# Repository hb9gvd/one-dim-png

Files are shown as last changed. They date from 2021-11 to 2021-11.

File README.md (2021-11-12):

# One Dim Pong
Arduino code and PCB Files, either Kicad and ready-to-order Gerber Files for One Dimensional Pong Game.
This repository exists for users to get files, open issues and make contributions.

To get started see [Firmware versions](#firmware-versions) part or look table of contents for more.

Table of contents
=================
* [Firmware versions](#firmware-versions)
* [Hardware schematic](#schematic)

Firmware Versions
============
To use with 100ms pulse coin counter 
[Arduino code and used libraries](./software/).

Schematic
============
Repository has updated Schematic made with Kicad. Some more information could be found 
[here](./hardware/kicad/).
Altough, find here printable 
[Schematic](./hardware/one-dim-pong.pdf) 
and have a look to the 
[PCB picture](./hardware/One-Dim-Pong-3D-V1.png).

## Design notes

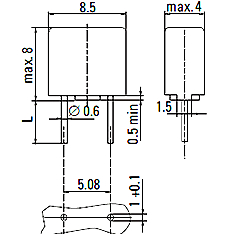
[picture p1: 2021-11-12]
hardware/THT-Fuse.jpg

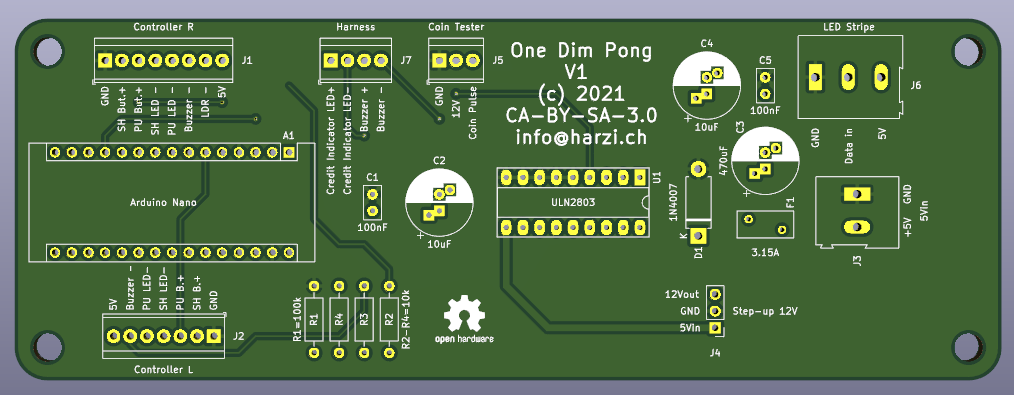
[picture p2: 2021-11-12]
hardware/One-Dim-Pong-3D-V1.png

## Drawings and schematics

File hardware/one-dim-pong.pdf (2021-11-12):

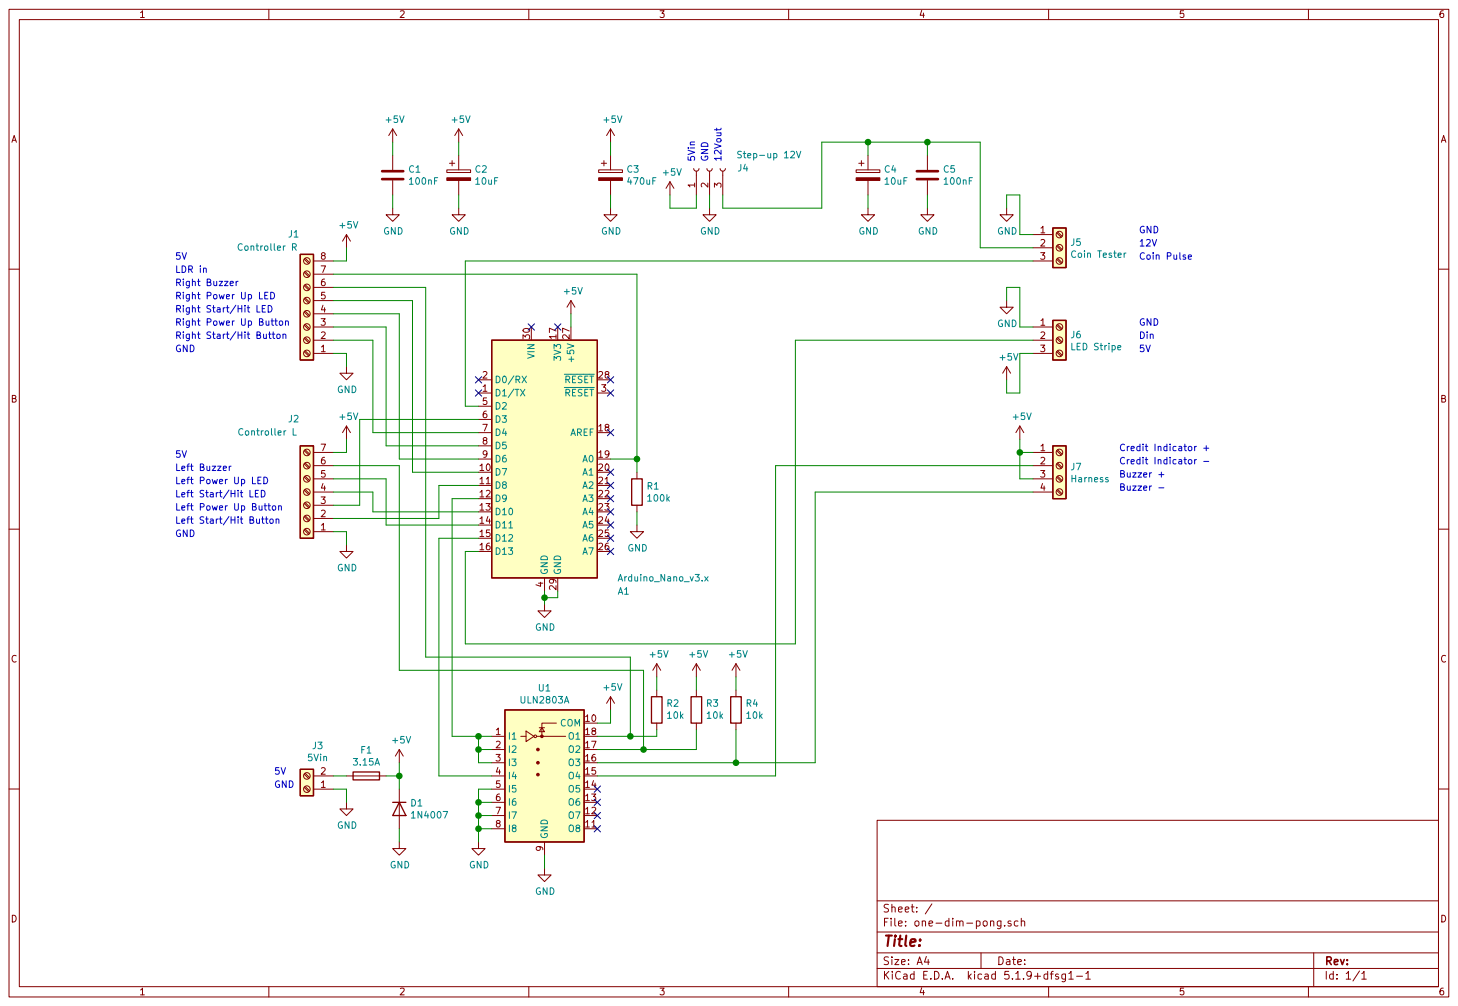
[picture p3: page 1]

Credit Indicator - Coin Pulse

Buzzer + Right Buzzer LDR in

Right Power Up LED
Right Start/Hit LED

Left Power Up LED
Buzzer - GND
Left Start/Hit LED
Left Power Up Button
Left Start/Hit Button

File: one-dim-pong.sch Sheet: / GND

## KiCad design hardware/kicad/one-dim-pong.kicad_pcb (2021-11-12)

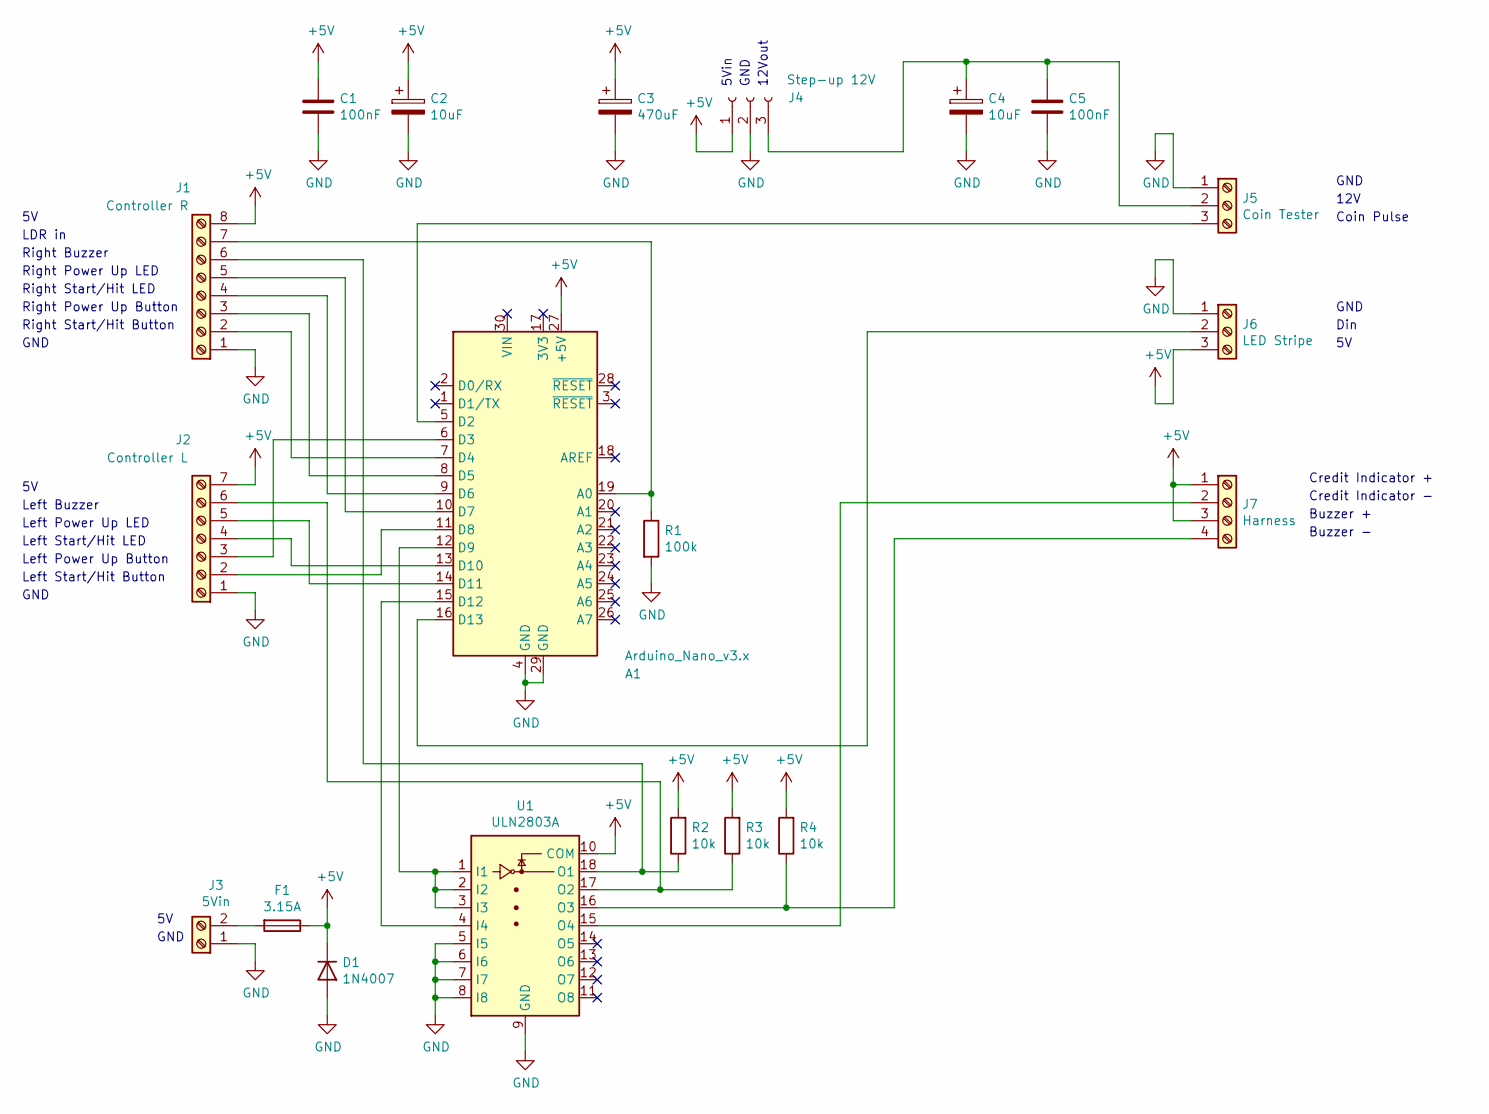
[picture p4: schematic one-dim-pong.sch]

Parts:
A1: Arduino_Nano_v3.x; Arduino_Nano
C1, C5: 100nF; C_Disc_D5.0mm_W2.5mm_P2.50mm
C2, C4: 10uF; CP_Radial_D10.0mm_P2.50mm_P5.00mm
C3: 470uF; CP_Radial_D10.0mm_P2.50mm_P5.00mm
D1: 1N4007; D_DO-15_P10.16mm_Horizontal
F1: 3.15A; Fuse_BelFuse_0ZRE0008FF_L8.3mm_W3.8mm
J1: Controller R; TerminalBlock_TE_282834-8_1x08_P2.54mm_Horizontal
J2: Controller L; TerminalBlock_TE_282834-7_1x07_P2.54mm_Horizontal
J3: 5Vin; TerminalBlock_Altech_AK300-2_P5.00mm
J4: Step-up 12V; PinHeader_1x03_P2.54mm_Vertical
J5: Coin Tester; TerminalBlock_TE_282834-3_1x03_P2.54mm_Horizontal
J6: LED Stripe; TerminalBlock_Altech_AK300-3_P5.00mm
J7: Harness; TerminalBlock_TE_282834-4_1x04_P2.54mm_Horizontal
R1: 100k; R_Axial_DIN0207_L6.3mm_D2.5mm_P10.16mm_Horizontal
R2, R3, R4: 10k; R_Axial_DIN0207_L6.3mm_D2.5mm_P10.16mm_Horizontal
U1: ULN2803A; DIP-18_W7.62mm_Socket_LongPads

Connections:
+5V: A1.27 (+5V), C1.1, C2.1, C3.1, D1.1 (K), F1.1, J1.8, J2.7, J4.1, J6.3, J7.1, J7.3, R2.2, R3.2, R4.2, U1.10 (COM)
GND: A1.4 (GND), A1.29 (GND), C1.2, C2.2, C3.2, C4.2, C5.2, D1.2 (A), J1.1, J2.1, J3.1, J4.2, J5.1, J6.1, R1.2, U1.5 (I5), U1.6 (I6), U1.7 (I7), U1.8 (I8), U1.9 (GND)
unnamed: A1.5 (D2), J5.3
unnamed: A1.6 (D3), J2.3
unnamed: A1.7 (D4), J1.2
unnamed: A1.8 (D5), J1.3
unnamed: A1.9 (D6), J1.4
unnamed: A1.10 (D7), J1.5
unnamed: A1.11 (D8), J2.2
unnamed: A1.12 (D9), U1.1 (I1), U1.2 (I2), U1.3 (I3)
unnamed: A1.13 (D10), J2.4
unnamed: A1.14 (D11), J2.5
unnamed: A1.15 (D12), U1.4 (I4)
unnamed: A1.16 (D13), J6.2
unnamed: A1.19 (A0), J1.7, R1.1
unnamed: C4.1, C5.1, J4.3, J5.2
unnamed: F1.2, J3.2
unnamed: J1.6, R2.1, U1.18 (O1)
unnamed: J2.6, R3.1, U1.17 (O2)
unnamed: J7.2, U1.15 (O4)
unnamed: J7.4, R4.1, U1.16 (O3)

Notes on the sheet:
Credit Indicator -
Credit Indicator +
Buzzer +
Buzzer -
5Vin
GND
12Vout
12V
Coin Pulse
Right Start/Hit Button
Right Power Up Button
Right Start/Hit LED
Right Power Up LED
Right Buzzer
LDR in
Left Start/Hit Button
Left Power Up Button
Left Start/Hit LED
Left Power Up LED
Left Buzzer
Din

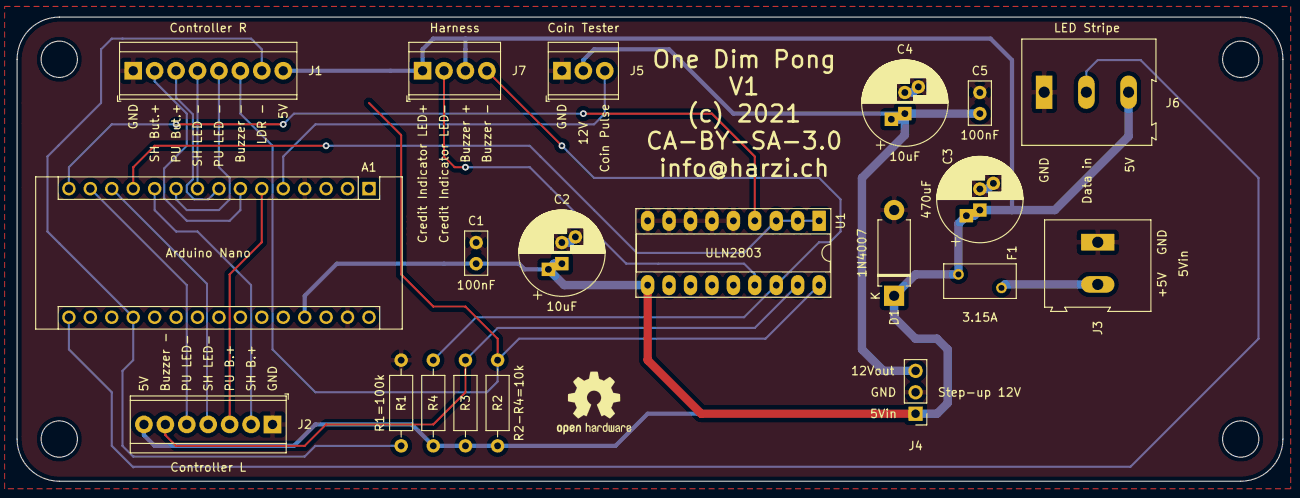
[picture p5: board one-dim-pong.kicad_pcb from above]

Board: 2 copper layers, 150.0 x 55.0 mm, 20 parts (0 on the bottom side), 21 nets.

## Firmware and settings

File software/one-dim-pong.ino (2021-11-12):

/*
 * Arduino 1D Pong Game with (60) WS2812B LEDs
 *
 * Copyright (C) 2015  B.Stultiens
 *
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
 * You should have received a copy of the GNU General Public License
 * along with this program.  If not, see <http://www.gnu.org/licenses/>.
 */
#include "Adafruit_NeoPixel.h"
#include "notes.h"

#define NELEM(x)		(sizeof(x) / sizeof((x)[0]))

int sensorPin    =    A0;   // select the input pin for ldr
int sensorValue  =     0;   // variable to store the value coming from the sensor
uint8_t bright;
#define minValue      930   // min. sensor value for lowest brightness
#define maxValue      1020  // max. sensor value for highest brightness
#define minBrightAnim 255   // lowest brightness
#define maxBrightAnim 255   // highest brightness

#define PIN_WSDATA    13  // LED data
#define PIN_BUT_LS    8   // Right start/hit button
#define PIN_BUT_LP    3   // Right power-up button
#define PIN_BUT_RS    4   // Left start/hit button
#define PIN_BUT_RP    5   // Left power-up button
#define PIN_BUT_COIN  2   // Coin pulse
#define PIN_SOUND     9   // Buzzer output (PB1/OC1A)
#define PIN_LED_RP    6   // Right start/hit button light
#define PIN_LED_RS    11  // Right power-up button light
#define PIN_LED_LP    10  // Left power-up button light
#define PIN_LED_LS    7   // Left start/hit button light
#define PIN_COINS_AVAILABLE 12

#define BL_NONE		0xff		// State changes of the button LEDs
#define BL_LS			0x01
#define BL_LP			0x02
#define BL_RS			0x04
#define BL_RP			0x08
#define BL_ALL		0x0f

#define NPIXELS			90		// Number of pixels to handle

#define H_STEPS			1542		// HSV maximum hue +1
#define H_YELLOW		257		// Hue for (hard) yellow color

#define ZONE_SIZE		7		// Bounce-back zone size
#define SHOW_LO			12		// Score dots intensity background
#define SHOW_HI			48		// Score dots intensity foreground
#define WIN_POINTS		5		// Points needed to win
#define TONE_INTERVAL		5		// Not every ball move should give a sound
int CREDIT  =       0;
#define COIN_PULSE  150

Adafruit_NeoPixel one_d = Adafruit_NeoPixel(NPIXELS, PIN_WSDATA, NEO_GRB | NEO_KHZ800);

// Events from buttons and timers
#define EV_BUT_LS_PRESS		0x01
#define EV_BUT_RS_PRESS		0x02
#define EV_BUT_LP_PRESS		0x04
#define EV_BUT_RP_PRESS		0x08
#define EV_COIN_INSERTED           0x10

#define EV_TIMER		0x20
#define EV_TIMEOUT		0x40
#define EV_TONETIMER		0x80

#define TIME_DEBOUNCE		8
#define TIME_IDLE		40
#define TIME_START_TIMEOUT	20000		// Go idle if nothing happens
#define TIME_RESUME_TIMEOUT	7500		// Auto-fire after timeout
#define TIME_BALL_BLINK		150
#define TIME_SPEED_MIN		10
#define TIME_SPEED_INTERVAL	3
#define TIME_POINT_BLINK	233
#define TIME_WIN_BLINK		85
#define TIME_LOCKOUT		250		// Prevent fast button-press to max. 4 times/s

#define TIME_TONE_SERVE		50		// Sound durations
#define TIME_TONE_BOUNCE	50
#define TIME_TONE_MOVE		25
#define TIME_TONE_SCORE		50

enum {
	ST_IDLE = 0,
	ST_START_L,
	ST_START_R,
	ST_MOVE_LR,
	ST_MOVE_RL,
	ST_ZONE_L,
	ST_ZONE_R,
	ST_POINT_L,
	ST_POINT_R,
	ST_RESUME_L,
	ST_RESUME_R,
	ST_WIN_L,
	ST_WIN_R,
};

static uint32_t oldtime;	// Previous' loop millis() value
static uint8_t thestate;	// Game state

static uint8_t bstate_ls;	// Button states
static uint8_t bstate_rs;
static uint8_t bstate_lp;
static uint8_t bstate_rp;
static uint8_t bstate_cn;
static uint8_t debtmr_ls;	// Button debounce timers
static uint8_t debtmr_rs;
static uint8_t debtmr_lp;
static uint8_t debtmr_rp;
static uint8_t debtmr_cn;
static uint16_t timer;		// General timer
static uint16_t timeout;	// Timeout timer (auto-start and goto idle)
static uint16_t tonetimer;	// Tone duration timer
static uint16_t lockout_l;	// Lockout timer to prevent pushing too often
static uint16_t lockout_r;
static uint16_t lock_coin;  // Timer to asure one CREDIT per COIN_PULSE only
static uint8_t ballblinkstate;	// Blinking ball at edge on/off
static uint8_t pointblinkcount;	// Blinking point when a side scores
static uint8_t ballpos;		// Current position of the ball
static uint16_t speed;		// Time between ball moves
static uint8_t speedup;		// Faster and faster replies counter
static uint8_t points_l;	// Score
static uint8_t points_r;
static uint8_t zone_l;		// Hit back zone
static uint8_t zone_r;
static uint8_t boost_l;		// Set if user boosted speed last round
static uint8_t boost_r;
static uint8_t boosted;		// Set if any user boosted until the ball reaches opposite side
static uint8_t tonecount;	// Interval counter for sound during move
static uint8_t tuneidx;		// Index to the running tune

static uint16_t ballh;		// Ball hue when moving boosted

// Twinkling lights when boosted (comet trail parts breaking off)
#define NTWINKLES	(NPIXELS / 8)
static struct {
	uint8_t		v;
	uint8_t 	pos;
	uint16_t	h;
} twinkles[NTWINKLES];

static uint32_t prng_val;	// Local random number generator state

typedef struct __note_t {
	uint8_t		note;
	uint16_t	duration;
} note_t;

/* Tone pitch table for 16MHz crystal */
static const uint16_t tone_pitch[NTONE_PITCH] PROGMEM = {
	61155, 57722, 54482, 51424, 48538, 45814, 43242, 40815, 38524, 36362 /* == 220Hz */, 34321, 32395,
	30577, 28860, 27240, 25711, 24268, 22906, 21620, 20407, 19261, 18180 /* == 440Hz */, 17160, 16197,
	15288, 14429, 13619, 12855, 12133, 11452, 10809, 10203,  9630,  9089 /* == 880Hz */,  8579,  8098,
	 7643,  7214,  6809,  6427,  6066,  5725,  5404,  5101,  4814,  4544,  4289,  4048,
	 3821,  3606,  3404,  3213,  3032,  2862,  2701,  2550,  2406,  2271,  2144,  2023,
	 1910,
};
static const note_t tune_win[] PROGMEM = {
	{ NOTE_Gs6, DUR_1_16 },
	{ NOTE_A6, DUR_1_16 },
	{ NOTE_Gs6, DUR_1_16 },
	{ NOTE_E6, DUR_1_16 },
	{ NOTE_Gs6, DUR_1_16 },
	{ NOTE_A6, DUR_1_16 },
	{ NOTE_Gs6, DUR_1_16 },
	{ NOTE_E6, DUR_1_16 },
	{ 0, DUR_1_8 },
	{ NOTE_D4, DUR_1_8 },
	{ NOTE_D4, DUR_1_8 },
	{ NOTE_B3, DUR_1_8 },
	{ NOTE_E4, DUR_1_8 },
	{ NOTE_D4, DUR_1_4 },
	{ NOTE_B3, DUR_1_4 },
	{ NOTE_D4, DUR_1_8 },
	{ NOTE_D4, DUR_1_8 },
	{ NOTE_B3, DUR_1_8 },
	{ NOTE_E4, DUR_1_8 },
	{ NOTE_D4, DUR_1_4 },
	{ NOTE_B3, DUR_1_4 },
};

#define sound_off()	do { TCCR1A = _BV(COM1A1); /* Set clear output */ } while(0)

/*
 * Local very fast Pseudo Random Number Generator (PRNG)
 * based on a simple LFSR design.
 */
static inline uint8_t lfsr_prng(void)
{
	uint8_t c = prng_val & 1;
	prng_val >>= 1;
	if(c)
		prng_val ^= 0xa6a6a6a6;
	return prng_val;
}

/*
 * Return the current state of a button.
 * Returns non-zero on button pressed.
 */
static inline uint8_t button_is_down(uint8_t pin)
{
	switch(pin) {
	case PIN_BUT_LS:	    return !debtmr_ls && !bstate_ls;
	case PIN_BUT_RS:	    return !debtmr_rs && !bstate_rs;
	case PIN_BUT_LP:	    return !debtmr_lp && !bstate_lp;
	case PIN_BUT_RP:	    return !debtmr_rp && !bstate_rp;
  case PIN_BUT_COIN:    return !debtmr_cn && !bstate_cn;
	}
	return 0;
}

/*
 * Debounce a button and return an event at the rising edge of the detection.
 * The rising edge ensures that there is no delay from pressing the button and
 * the event propagating. It is a prerequisite that the input line is not
 * glitchy.
 * A release event may be generated if the routine is slightly modified.
 */
static inline uint8_t do_debounce(uint8_t tdiff, uint8_t *bstate, uint8_t *debtmr, uint8_t pin, uint8_t ev)
{
	if(0 == *debtmr) {
		uint8_t state = digitalRead(pin);
		if(state != *bstate) {
			*debtmr = TIME_DEBOUNCE;
			if(!(*bstate = state))
				return ev;	// Event on High-to-Low transition of input
			// else
			//  return release_event_value
		}
	} else {
		if(*debtmr >= tdiff)
			*debtmr -= tdiff;
		else
			*debtmr = 0;
	}
	return 0;
}

/*
 * Timer countdown and return an event on timer reaching zero.
 */
static inline uint8_t do_timer(uint8_t tdiff, uint16_t *tmr, uint8_t ev)
{
	if(0 != *tmr) {
		if(*tmr >= tdiff)
			*tmr -= tdiff;	// Timer countdown
		else
			*tmr = 0;
		// Set event when done counting
		if(0 == *tmr)
			return ev;
	}
	return 0;
}

/*
 * Set the speaker to generate a tone
 */
static inline void set_tone(uint16_t note, uint16_t duration)
{
	tonetimer = duration;
	if(note && note <= NTONE_PITCH) {
		OCR1A = pgm_read_word(&tone_pitch[note-1]);
		TCCR1A = _BV(COM1A0);	/* Set toggle output */
		TCNT1 = 0;
	} else
		sound_off();
}

/*
 * Play the next note of the tune
 */
static inline void tune_next()
{
	if(tuneidx < NELEM(tune_win)) {
		uint16_t n = pgm_read_byte(&tune_win[tuneidx].note);
		uint16_t d = pgm_read_word(&tune_win[tuneidx].duration);
		set_tone(n, d);
		tuneidx++;
	} else
		set_tone(0, 0);
}

/*
 * Draw the left and right zones where the ball may be hit back.
 */
static void draw_sides()
{
	for(uint8_t i = 0; i < zone_l-1; i++) {
		one_d.setPixelColor(i, 0, 64, 64);
	}
	one_d.setPixelColor(0, 0, 64, 64);
	for(uint8_t i = 0; i < zone_r-1; i++) {
		one_d.setPixelColor(NPIXELS-1-i, 0, 64, 64);
	}
	one_d.setPixelColor(NPIXELS-1, 0, 64, 64);
}

/*
 * Draw the ball with a tail of five pixels in diminishing intensity.
 * The ball changes color when boosted and there is a chance of parts "falling
 * off" which will twinkle for a while.
 */
static void draw_ball(int8_t dir, uint8_t pos)
{
	uint8_t c = 255;
	uint8_t tail;

	/* Adjust the tail-length to the speed of the ball.
	 * We use 'timer' here because a boost changes the speed and the timer
	 * is set before we draw the ball.
	 */
	if(timer <= 3)
		tail = 7;	// High speed, long tail
	else if(timer <= 12)
		tail = 6;
	else
		tail = 5;	// Default to 5 pixels

	if(boosted) {
		ballh += 75;	// About three times round the circle on the course
		if(ballh >= H_STEPS)
			ballh -= H_STEPS;
		/* 1 in 4 chance of adding a twinkle */
		if(!(lfsr_prng() & 0x03)) {
			for(uint8_t i = 0; i < NELEM(twinkles); i++) {
				if(!twinkles[i].v) {
					/* Add to first free slot */
					twinkles[i].v = 255;
					twinkles[i].pos = pos;
					twinkles[i].h = ballh;
					break;
				}
			}
		}
		/* Draw color ball */
		for(uint8_t i = 0; i < tail && pos >= 0 && pos < NPIXELS; i++) {
			one_d.setPixelColorHsv(pos, ballh, 255, c);
			c >>= 1;
			pos -= dir;
		}
		/* Add twinkling lights */
		for(uint8_t i = 0; i < NELEM(twinkles); i++) {
			if(twinkles[i].v) {
				one_d.setPixelColorHsv(twinkles[i].pos, twinkles[i].h, 128, twinkles[i].v);
				/* 1 in 8 chance to increase the intensity */
				if(!(lfsr_prng() & 0x07)) {
					twinkles[i].v <<= 4;
					twinkles[i].v |= 0x0f;
				} else {
					twinkles[i].v >>= 1;
				}
			}
		}
	} else {
		for(uint8_t i = 0; i < tail && pos >= 0 && pos < NPIXELS; i++) {
			one_d.setPixelColor(pos, c, c, 0);
			c >>= 1;
			pos -= dir;
		}
	}

}

/*
 * Draw the playing field consisting of the zones and the points scored so far.
 */
static void draw_course(uint8_t v)
{
	one_d.clear();
	draw_sides();
	if(v) {
		for(uint8_t i = 0; i < points_l; i++) {
			one_d.setPixelColor(NPIXELS/2-1-(2*i+0), v, 0, 0);
			one_d.setPixelColor(NPIXELS/2-1-(2*i+1), v, 0, 0);
		}
		for(uint8_t i = 0; i < points_r; i++) {
			one_d.setPixelColor(NPIXELS/2+(2*i+0), 0, v, 0);
			one_d.setPixelColor(NPIXELS/2+(2*i+1), 0, v, 0);
		}
	}
}

/*
 * Animate the game idle situation with following content:
 * - A rainbow pattern
 * - Ball bouncing left-right-left-right
 * - Score animation
 */
static uint16_t ai_h;
static uint8_t ai_state;
static uint8_t ai_pos;

static void animate_idle_init(void)
{
	ai_h = 0;
	ai_state = 0;
}

static void animate_idle(void)
{
	switch(ai_state) {
	case 0:
	case 1:
	case 2:
	case 3:
		/* Rainbow pattern */
		for(uint8_t i = 0; i < NPIXELS; i++) {
			uint16_t h = ai_h + (i << 4);
			if(h >= H_STEPS)
				h -= H_STEPS;
			one_d.setPixelColorHsv(i, h, 255, 128);
		}
		ai_h += H_STEPS/60;
		if(ai_h >= H_STEPS) {
			ai_h -= H_STEPS;
			ai_pos = 0;
			ai_state++;
		}
		break;
	case 4:
	case 6:
		/* Ball left-to-right */
		draw_course(0);
		draw_ball(1, ai_pos++);
		if(ai_pos >= NPIXELS) {
			ai_state++;
		}
		break;
	case 5:
	case 7:
		/* Ball right-to-left */
		draw_course(0);
		draw_ball(-1, --ai_pos);
		if(!ai_pos) {
			ai_state++;
		}
		break;
	case 8:
	case 10:
		/* Score blinkenlights */
		sensorValue = analogRead(sensorPin);
    bright=map(constrain(sensorValue,minValue,maxValue),minValue,maxValue,minBrightAnim,maxBrightAnim);
    draw_course(0);
    		for(uint8_t i = 0; i < ai_pos; i++) {
			one_d.setPixelColor(NPIXELS/2-1-i, bright, 0, 0);
			one_d.setPixelColor(NPIXELS/2+i, 0, bright, 0);
		}
		if(++ai_pos >= NPIXELS/2) {
			ai_state++;
			ai_pos = 0;
		}
		break;

	case 9:
	case 11:
    sensorValue = analogRead(sensorPin);
    bright=map(constrain(sensorValue,minValue,maxValue),minValue,maxValue,minBrightAnim,maxBrightAnim);
		draw_course(0);
		for(uint8_t i = 0; i < NPIXELS/2-ai_pos; i++) {
			one_d.setPixelColor(NPIXELS/2-1-i, bright, 0, 0);
			one_d.setPixelColor(NPIXELS/2+i, 0, bright, 0);
		}
		if(++ai_pos >= NPIXELS/2) {
			ai_state++;
			ai_pos = 0;
		}
		break;

	default:
		ai_state = 0;
		break;
	}
	one_d.show();
}

/*
 * Animate a winner. Flash the winning side's points.
 */
static uint8_t aw_state;
static void animate_win_init()
{
	aw_state = 0;
}

static uint8_t animate_win(uint8_t side)
{
	uint32_t clr;
	uint8_t pos;
  sensorValue = analogRead(sensorPin);
  bright=map(constrain(sensorValue,minValue,maxValue),minValue,maxValue,minBrightAnim,maxBrightAnim);
  if(side) {
		clr = Adafruit_NeoPixel::Color(0, bright, 0);
		pos = NPIXELS/2;
	} else {
		clr = Adafruit_NeoPixel::Color(bright, 0, 0);
		pos = 0;
	}

	one_d.clear();
	if(aw_state < 20) {
		if(aw_state & 0x01) {
			for(uint8_t i = 0; i < NPIXELS/2; i++) {
				one_d.setPixelColor(pos+i, clr);
			}
		}
	} else if(aw_state < 50) {
		for(uint8_t i = 0; i < aw_state - 20; i++) {
			one_d.setPixelColor(pos+i, clr);
		}
	} else if(aw_state < 80) {
		for(uint8_t i = aw_state - 50; i < NPIXELS/2; i++) {
			one_d.setPixelColor(pos+i, clr);
		}
	} else if(aw_state < 110) {
		for(uint8_t i = 0; i < aw_state - 80; i++) {
			one_d.setPixelColor(NPIXELS/2-1-i+pos, clr);
		}
	} else if(aw_state < 140) {
		for(uint8_t i = aw_state - 110; i < NPIXELS/2; i++) {
			one_d.setPixelColor(NPIXELS/2-1-i+pos, clr);
		}
	}
	one_d.show();
	return ++aw_state < 140;
}
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
void loop()
{
	uint32_t now;
	uint8_t tdiff = (now = millis()) - oldtime;
	uint8_t events = 0;
      
	/* Handle buttons and timers on (just about) every millisecond */
	if(tdiff) {
		oldtime = now;
		events |= do_debounce(tdiff, &bstate_ls, &debtmr_ls, PIN_BUT_LS, EV_BUT_LS_PRESS);
		events |= do_debounce(tdiff, &bstate_rs, &debtmr_rs, PIN_BUT_RS, EV_BUT_RS_PRESS);
		events |= do_debounce(tdiff, &bstate_lp, &debtmr_lp, PIN_BUT_LP, EV_BUT_LP_PRESS);
		events |= do_debounce(tdiff, &bstate_rp, &debtmr_rp, PIN_BUT_RP, EV_BUT_RP_PRESS);
    events |= do_debounce(tdiff, &bstate_cn, &debtmr_cn, PIN_BUT_COIN,   EV_COIN_INSERTED);
		events |= do_timer(tdiff, &timer, EV_TIMER);
		events |= do_timer(tdiff, &timeout, EV_TIMEOUT);
		events |= do_timer(tdiff, &tonetimer, EV_TONETIMER);
		do_timer(tdiff, &lockout_l, 0);
		do_timer(tdiff, &lockout_r, 0);
    do_timer(tdiff, &lock_coin, 0);
	}

	if(is_game_state(thestate)) {
		// If the lockout timer is running, squash the button event
		if(lockout_l){
			events &= ~EV_BUT_LS_PRESS;}
		if(lockout_r){
			events &= ~EV_BUT_RS_PRESS;}
	}

	// A button press activates the lockout timer
	if(chk_ev(EV_BUT_LS_PRESS)){
		lockout_l = TIME_LOCKOUT;}
	if(chk_ev(EV_BUT_RS_PRESS)){
		lockout_r = TIME_LOCKOUT;}


  // If the COIN_PULSE timer is running, squash the COINevent
  if(lock_coin){
      events &= ~EV_COIN_INSERTED;
  }

  // A Coinpulse activates the lock_coin timer
  if(chk_ev(EV_COIN_INSERTED)){
    lock_coin = COIN_PULSE;
  }
	
	// Show indicators on buttons which are active
	button_leds_set();
  // In every state check, if coins are inserted so check it before entereing the state machine logic below
  
  if(chk_ev(EV_COIN_INSERTED)) {
      ++CREDIT;
    }  

	switch(thestate) {
	case ST_IDLE:
  // If CREDIT available, decrease CREDIT and start game
		if(chk_ev(EV_BUT_LS_PRESS) && (CREDIT)) {
    	--CREDIT;
			set_state(ST_START_L);
    } else if(chk_ev(EV_BUT_RS_PRESS) && (CREDIT)) {
    	--CREDIT;
			set_state(ST_START_R);
		} else if(chk_ev(EV_TIMER)) {
			timer = TIME_IDLE;
			animate_idle();
		}
		break;

	// Game is started, waiting for left player to serve the ball
	case ST_START_L:
  	if(chk_ev(EV_BUT_LS_PRESS)) {
			set_state(ST_MOVE_LR);
		} else if(chk_ev(EV_TIMEOUT)) {
			set_state(ST_IDLE);
		} else if(chk_ev(EV_TIMER)) {
			timer = TIME_BALL_BLINK;
			if(ballblinkstate)
				one_d.setPixelColor(ballpos, 255, 128, 0);
			else
				one_d.setPixelColor(ballpos, 0, 0, 0);
			one_d.show();
			ballblinkstate = !ballblinkstate;
		}
		break;

	// Game is started, waiting for right player to serve the ball
	case ST_START_R:
		if(chk_ev(EV_BUT_RS_PRESS)) {
			set_state(ST_MOVE_RL);
		} else if(chk_ev(EV_TIMEOUT)) {
			set_state(ST_IDLE);
		} else if(chk_ev(EV_TIMER)) {
			timer = TIME_BALL_BLINK;
			if(ballblinkstate)
				one_d.setPixelColor(ballpos, 255, 128, 0);
			else
				one_d.setPixelColor(ballpos, 0, 0, 0);
			one_d.show();
			ballblinkstate = !ballblinkstate;
		}
		break;

	case ST_MOVE_LR:
  	if(chk_ev(EV_TIMER)) {
			if(!--tonecount) {
				set_tone(NOTE_G4, TIME_TONE_MOVE);
				tonecount = TONE_INTERVAL;
			}
			speed_to_timer();
			draw_course(SHOW_LO);
			draw_ball(1, ballpos);
			one_d.show();
			ballpos++;
			if(NPIXELS-1 - ballpos <= zone_r)
				set_state(ST_ZONE_R);
		}
		break;

	// Ball is moving right-to-left outside the playback zone
	case ST_MOVE_RL:
		if(chk_ev(EV_TIMER)) {
			if(!--tonecount) {
				set_tone(NOTE_G4, TIME_TONE_MOVE);
				tonecount = TONE_INTERVAL;
			}
			speed_to_timer();
			draw_course(SHOW_LO);
			draw_ball(-1, ballpos);
			one_d.show();
			ballpos--;
			if(ballpos <= zone_l)
				set_state(ST_ZONE_L);
		}
		break;
	case ST_ZONE_L:
		if(chk_ev(EV_BUT_LS_PRESS)) {
			set_tone(NOTE_G3, TIME_TONE_BOUNCE);
			set_state(ST_MOVE_LR);
			// Changing speed is done after the state-change's exit/entry action
			if(zone_l > 1 && button_is_down(PIN_BUT_LP)) {
				zone_l--;
				boosted = 1;
				ballh = H_YELLOW;
				speed_to_timer();
				boost_l++;
			}
		} else if(chk_ev(EV_TIMER)) {
			if(!ballpos) {
				set_tone(NOTE_C5, TIME_TONE_SCORE);
				if(++points_r >= WIN_POINTS)
					set_state(ST_WIN_R);
				else
					set_state(ST_POINT_R);
			} else {
				speed_to_timer();
				ballpos--;
			}
			draw_course(SHOW_LO);
			draw_ball(-1, ballpos);
			one_d.show();
		}
		break;

	// Ball is in the right playback zone, waiting for hit/score
	case ST_ZONE_R:
		if(chk_ev(EV_BUT_RS_PRESS)) {
			set_tone(NOTE_G3, TIME_TONE_BOUNCE);
			set_state(ST_MOVE_RL);
			// Changing speed is done after the state-change's exit/entry action
			if(zone_r > 1 && button_is_down(PIN_BUT_RP)) {
				zone_r--;
				speed_to_timer();
				boosted = 1;
				ballh = H_YELLOW;
				boost_r++;
			}
		} else if(chk_ev(EV_TIMER)) {
			if(ballpos == NPIXELS-1) {
				set_tone(NOTE_C5, TIME_TONE_SCORE);
				if(++points_l >= WIN_POINTS)
					set_state(ST_WIN_L);
				else
					set_state(ST_POINT_L);
			} else {
				speed_to_timer();
				ballpos++;
			}
			draw_course(SHOW_LO);
			draw_ball(1, ballpos);
			one_d.show();
		}
		break;

	// Left player scored, animate point
	case ST_POINT_L:
		if(chk_ev(EV_BUT_LS_PRESS)) {
			set_state(ST_RESUME_L);
		} else if(chk_ev(EV_TIMER)) {
			timer = TIME_POINT_BLINK;
			draw_course(SHOW_HI);
			if(!(pointblinkcount & 0x01)) {
				one_d.setPixelColor(NPIXELS/2-1-(2*(points_l-1)+0), 0, 0, 0);
				one_d.setPixelColor(NPIXELS/2-1-(2*(points_l-1)+1), 0, 0, 0);
			} else {
				one_d.setPixelColor(NPIXELS/2-1-(2*(points_l-1)+0), 255, 0, 0);
				one_d.setPixelColor(NPIXELS/2-1-(2*(points_l-1)+1), 255, 0, 0);
			}
			one_d.show();
			if(!--pointblinkcount)
				set_state(ST_RESUME_L);
		}
		break;

	// Right player scored, animate point
	case ST_POINT_R:
		if(chk_ev(EV_BUT_RS_PRESS)) {
			set_state(ST_RESUME_R);
		} else if(chk_ev(EV_TIMER)) {
			timer = TIME_POINT_BLINK;
			draw_course(SHOW_HI);
			if(!(pointblinkcount & 0x01)) {
				one_d.setPixelColor(NPIXELS/2+(2*(points_r-1)+0), 0, 0, 0);
				one_d.setPixelColor(NPIXELS/2+(2*(points_r-1)+1), 0, 0, 0);
			} else {
				one_d.setPixelColor(NPIXELS/2+(2*(points_r-1)+0), 0, 255, 0);
				one_d.setPixelColor(NPIXELS/2+(2*(points_r-1)+1), 0, 255, 0);
			}
			one_d.show();
			if(!--pointblinkcount)
				set_state(ST_RESUME_R);
		}
		break;

	// Left player previously scored and must serve again (or timeout to auto-serve)
	case ST_RESUME_L:
		if(chk_ev(EV_BUT_LS_PRESS | EV_TIMEOUT)) {
			set_state(ST_MOVE_LR);
			set_tone(NOTE_F3, TIME_TONE_SERVE);
		} else if(chk_ev(EV_TIMER)) {
			timer = TIME_BALL_BLINK;
			if(ballblinkstate)
				one_d.setPixelColor(ballpos, 255, 128, 0);
			else
				one_d.setPixelColor(ballpos, 0, 0, 0);
			one_d.show();
			ballblinkstate = !ballblinkstate;
		}
		break;

	// Right player previously scored and must serve again (or timeout to auto-serve)
	case ST_RESUME_R:
		if(chk_ev(EV_BUT_RS_PRESS | EV_TIMEOUT)) {
			set_state(ST_MOVE_RL);
			set_tone(NOTE_F3, TIME_TONE_SERVE);
		} else if(chk_ev(EV_TIMER)) {
			timer = TIME_BALL_BLINK;
			if(ballblinkstate)
				one_d.setPixelColor(ballpos, 255, 128, 0);
			else
				one_d.setPixelColor(ballpos, 0, 0, 0);
			one_d.show();
			ballblinkstate = !ballblinkstate;
		}
		break;

	// A player won the game, animate the winning side
	case ST_WIN_L:
	case ST_WIN_R:
		if(chk_ev(EV_TONETIMER)) {
			events &= ~EV_TONETIMER;	// Remove the event so we don't get messed up with a set_tone(0, 0) below call
			tune_next();
		}
		if(chk_ev(EV_BUT_LS_PRESS) && (CREDIT)) {
      --CREDIT;
			set_state(ST_START_L);
		} else if(chk_ev(EV_BUT_RS_PRESS) && (CREDIT)) {
      --CREDIT;
			set_state(ST_START_R);
		} else if(chk_ev(EV_TIMER)) {
			timer = TIME_WIN_BLINK;
			if(!animate_win(thestate == ST_WIN_R)){
        set_state(ST_IDLE);
      }
		}
		break;

	// If we get confused, start at idle...
	default:
		set_state(ST_IDLE);
		break;
	}

	/* The sound timer is async to the rest */
	/* Alternative is to handle it in each and every state */
	if(chk_ev(EV_TONETIMER))
		set_tone(0, 0);

}

// vim: syn=cpp

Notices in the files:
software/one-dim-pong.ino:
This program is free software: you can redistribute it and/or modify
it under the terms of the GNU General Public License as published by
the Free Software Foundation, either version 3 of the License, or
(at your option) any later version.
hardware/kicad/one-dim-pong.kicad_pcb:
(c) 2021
